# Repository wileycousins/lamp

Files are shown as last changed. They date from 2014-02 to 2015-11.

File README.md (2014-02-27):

# lamp
Another object from [Wiley Cousins](https://wileycousins.com) and [Trig Projects](http://trigprojects.com)

Lamp is a smart LED lamp system that has two jobs: letting you know about things and looking pretty. Currently in development.

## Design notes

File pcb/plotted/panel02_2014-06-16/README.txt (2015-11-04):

Lamp v0.2 Panel
Wiley Cousins, LLC.
2014-06-16

Prepared by Michael Cousins
michael@wileycousins.com
(281) 210-6984

File overview:
lamp-main-append-F_Cu.gtl       -  top copper
lamp-main-append-F_Mask.gts     -  top soldermask
lamp-main-append-F_SilkS.gto    -  top silkscreen
lamp-main-append-B_Cu.gbl       -  bottom copper
lamp-main-append-B_Mask.gts     -  bottom soldermask
lamp-main-append-Edge_Cuts.gbr  -  board outline
lamp-main-append-Eco2_User.gbr  -  dimensions
lamp-main-append.drl            -  drill file

Board outline:
  - 0.01" lines indicate outline
  - 0.005" lines indicate score lines

Drill file:
  - Excellon format
  - 2:4 precision
  - No zero suppression

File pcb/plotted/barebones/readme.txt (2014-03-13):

Lamp v0.1 Bare-bones Panel
Wiley Cousins, LLC.
2014-03-13

Prepared by Michael Cousins
michael@wileycousins.com
(281) 210-6984

File overview:
lamp-pcb-F_Cu.gtl       -  top copper
lamp-pcb-B_Cu.gbl       -  bottom copper
lamp-pcb-Edge_Cuts.gbr  -  board outline
lamp-pcb.drl            -  drill file

Drill file:
  - Excellon format
  - 2:4 precision
  - No zero suppression

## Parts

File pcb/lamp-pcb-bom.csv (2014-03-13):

24pF,2,"C2 C3",,Samsung Electro-Mechanics America, Inc,CL10C240JB8NCNC,Digikey,1276-2242-1-ND,http://www.digikey.com/product-detail/en/CL10C240JB8NCNC/1276-2242-1-ND/3890328
0.1uF,1,"C1",,On Hand
0.1uF,6,"C4 C5 C6 C9 C10 C11",,On hand
10uF,1,"C7",,Taiyo Yuden,TMK316F106ZL-T,Digikey,587-1353-1-ND,http://www.digikey.com/product-detail/en/TMK316F106ZL-T/587-1353-1-ND/931130
22uF,1,"C8",,Taiyo Yuden,LMK316F226ZL-T,Digikey,587-1356-1-ND,http://www.digikey.com/product-detail/en/LMK316F226ZL-T/587-1356-1-ND/931133
ATMEGA328P,1,"IC1",
LM1117,1,"IC2",,Diodes Incorporated,AZ1117CH-5.0TRG1,Digikey,AZ1117CH-5.0TRG1DICT-ND,http://www.digikey.com/product-detail/en/AZ1117CH-5.0TRG1/AZ1117CH-5.0TRG1DICT-ND/4505207
TLC5973,1,"IC3",,Texas Instruments,TLC5973D
5V_OUT,1,"J1",
LED_CARD_BOTTOM,1,"J2",
CREE-CLV6A-FKB,2,"LED1 LED2",,Cree,CLV6A-FKB-CK1P1G1BB7R3R3,Digikey,CLV6A-FKB-CK1P1G1BB7R3R3CT-ND,http://www.digikey.com/product-detail/en/CLV6A-FKB-CK1P1G1BB7R3R3/CLV6A-FKB-CK1P1G1BB7R3R3CT-ND/2166014
HEART,1,"LED3",,On hand
PWR,1,"LED4",,On hand
7-12V_IN,1,"P1",
AVR_ISP,1,"P2",
SERIAL,1,"P3",
LEDSTACK,3,"P4 P5 P6",
LED_CARD_TOP,1,"P7",
SER_SHORT,1,"P8",
1kΩ,3,"R5 R6 R7",,On hand
2kΩ,1,"R4",,On hand
10kΩ,3,"R1 R2 R3",,On hand
TOP,1,"S1",,C&K Components,JS102011SAQN,Digikey,401-1999-1-ND,http://www.digikey.com/product-detail/en/JS102011SAQN/401-1999-1-ND/1640114
14.7456MHz,1,"Y1",,Abracon Corporation,ABLS-14.7456MHZ-B4-T,Digikey,535-10223-1-ND,http://www.digikey.com/product-detail/en/ABLS-14.7456MHZ-B4-T/535-10223-1-ND/2184258

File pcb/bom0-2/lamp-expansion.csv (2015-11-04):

Id | Designator | Package | Quantity | Designation | Supplier and ref
1 | AE1 | johanson:JOHANSON-2500AT44M0400_2.4GHz-chip-antenna | 1 | 2500AT44M0400E
2 | C1,C9,C15,C27,C28 | passive-smd:0603(1608m) | 5 | 1uF
3 | C4,C14,C16,C30 | passive-smd:0603(1608m) | 4 | 0.1uF
4 | C5,C6,C18 | passive-smd:0603(1608m) | 3 | 47pF
5 | C7,C13,C8,C31 | passive-smd:1206(3216m) | 4 | 10uF
6 | C19,C3 | capacitor:PANA-D_CHEMI-F_SM-ALUMINUM | 2 | 100uF
7 | C20 | passive-smd:1206(3216m) | 1 | 22uF
8 | C22 | passive-smd:0603(1608m) | 1 | 2.2pF
9 | C24 | passive-smd:0603(1608m) | 1 | 10pF
10 | C26 | passive-smd:0603(1608m) | 1 | DNP(10pF)
11 | F1 | passive-smd:1206(3216m) | 1 | 2A
12 | IC2 | sot:SOT23-5 | 1 | MCP73811
13 | IC6 | sot:SOT223 | 1 | LM1117_5.0
14 | IC7 | sop:SSOP16 | 1 | FT230X_SOP
15 | IC9 | texas:CC3000 | 1 | CC3000
16 | J1 | connect-sm:MICROUSB_sm | 1 | MICROUSB
17 | J3 | sip:SIP6 | 1 | SERIAL
18 | J4 | sip:SIP5 | 1 | 5PIN_INPUT
19 | J5,J7 | sip:SIP2 | 2 | 2PIN_POWER
20 | J8 | connect-thru:2x3-ARRAY_P100mil | 1 | AVR_ISP
21 | J9 | connect-sm:U.FL-COAX | 1 | UF.L
22 | JP3 | jumper:SOLDER-JUMPER_2-WAY | 1 | MODE-SEL
23 | L2 | passive-smd:0603(1608m) | 1 | DNP
24 | L3 | passive-smd:0603(1608m) | 1 | 2.2nH
25 | LED1 | led:0603(1608m)-SM-LED | 1 | YEL
26 | LED2 | led:0603(1608m)-SM-LED | 1 | GRN
27 | Q1 | sot:SOT23 | 1 | 2N7002
28 | R1 | passive-smd:0603(1608m) | 1 | 100kΩ
29 | R2,R3 | passive-smd:0603(1608m) | 2 | 27Ω
30 | R4 | passive-smd:0603(1608m) | 1 | 10k
31 | R5,R10 | passive-smd:0603(1608m) | 2 | 10kΩ
32 | R6 | passive-smd:0603(1608m) | 1 | 47kΩ
33 | R7 | passive-smd:0603(1608m) | 1 | 51k
34 | R8,R9 | passive-smd:0603(1608m) | 2 | 330Ω
35 | R12,R13 | passive-smd:0603(1608m) | 2 | 0Ω
36 | TP1,TP2,TP3,TP4,TP5 | connect-thru:1-PIN | 5 | TEST
37 | TP6,TP7,TP8,TP9,TP10 | connect-thru:1-PIN | 5 | PIN
38 | C29 | passive-smd:0603(1608m) | 1 | 2.2nF
39 | IC1 | sop:SOP8_ep | 1 | PAM2421
40 | L1 | inductor:SM-INDUCTOR_6mmX6mm | 1 | 6.8uH
41 | D2,D6 | diode:MICROSMP | 2 | 2A
42 | D3,D4 | diode:DO-214AC | 2 | 3A
43 | IC3 | sot:CHIPFET-1206-8 | 1 | NTHD3101F
44 | J2 | connect-thru:CUI-PJ-102A_dc-barrel-jack | 1 | DCIN
45 | VR2,VR3,VR1 | bourns:BOURNS-PTA2043_20mm-slide-pot | 3 | 100kΩ
46 | BT1 | connect-thru:JST-S2B-PH-K_right-angle-jack | 1 | LIPO
47 | S1 | switch:SPST-2-PIN_6mm_thru | 1 | SPST

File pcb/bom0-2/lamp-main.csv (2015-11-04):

Id | Designator | Package | Quantity | Designation | Supplier and ref
1 | IC1 | qfp:TQFP32_P0.8mm | 1 | ATMEGA328P
2 | IC2 | sot:SOT223 | 1 | DNP(LM1117_3.3)
3 | P1 | sip:SIP2 | 1 | VLED_IN
4 | P2 | connect-thru:2x3-ARRAY_P100mil | 1 | AVR_ISP
5 | P3 | sip:SIP6 | 1 | SERIAL
6 | P4,P5,P6 | sip:SIP5 | 3 | LEDSTACK
7 | P7 | sip:SIP5 | 1 | USER-INPUT
8 | P8 | sip:SIP2 | 1 | EXTRA-ADC
9 | P10 | sip:SIP2 | 1 | V_IN
10 | Y1 | crystal:ABRACON-ABM2_xtal | 1 | 8MHz
11 | JP1 | jumper:SOLDER-JUMPER_1-WAY | 1 | VLED-VIN-JUMP
12 | C1,C4,C5,C6,C9 | capacitor:0603(1608m)-CHIP-CAP | 5 | 0.1uF
13 | C2,C3 | capacitor:0603(1608m)-CHIP-CAP | 2 | 24pF
14 | C7 | capacitor:1206(3216m)-CHIP-CAP | 1 | DNP(10uF)
15 | C8 | capacitor:1206(3216m)-CHIP-CAP | 1 | DNP(22uF)
16 | R1,R2,R3 | resistor:0603(1608m)-CHIP-RESISTOR | 3 | 10kΩ
17 | R6,R7 | resistor:0603(1608m)-CHIP-RESISTOR | 2 | 1kΩ
18 | LED1,LED2 | led:0603(1608m)-SM-LED | 2 | RED

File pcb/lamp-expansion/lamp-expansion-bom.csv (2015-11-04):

Source: | /media/sf_projects/lamp/pcb/lamp-expansion/lamp-expansion.sch
Date: | Fri 15 Aug 2014 07:13:58 PM EDT
Tool: | eeschema (2014-03-19 BZR 4756)-product
Component Count: | 67
Individual Components:
Item | Qty | Reference(s) | Value | LibPart | Footprint | Datasheet | Distrib. Part | Distributor | Manuf. Part | Manufacturer
 |  | AE1 | 2500AT44M0400E | standard:ANTENNA | johanson:JOHANSON-2500AT44M0400_2.4GHz-chip-antenna |  | 712-1403-1-ND | Digikey | 2500AT44M0400E | Johanson Technology Inc
 |  | BT1 | LIPO | connector:LIPO | connect-thru:JST-S2B-PH-K_right-angle-jack
 |  | C1 | 1uF | standard:C | passive-smd:0603(1608m)
 |  | C13 | 10uF | standard:C_POL | passive-smd:1206(3216m) |  | 587-1353-1-ND | Digikey | TMK316F106ZL-T | Taiyo Yuden
 |  | C14 | 0.1uF | standard:C | passive-smd:0603(1608m)
 |  | C15 | 1uF | standard:C | passive-smd:0603(1608m)
 |  | C16 | 0.1uF | standard:C | passive-smd:0603(1608m)
 |  | C18 | 47pF | standard:C | passive-smd:0603(1608m)
 |  | C19 | 100uF | standard:C_POL | capacitor:PANA-D_CHEMI-F_SM-ALUMINUM |  | 565-2089-1-ND | Digikey | EMVA160ADA101MF55G | United Chemi-Con
 |  | C20 | 22uF | standard:C_POL | passive-smd:1206(3216m) |  | 587-1356-1-ND | Digikey | LMK316F226ZL-T | Taiyo Yuden
 |  | C22 | 2.2pF | standard:C | passive-smd:0603(1608m)
 |  | C24 | 10pF | standard:C | passive-smd:0603(1608m)
 |  | C26 | DNP(10pF) | standard:C | passive-smd:0603(1608m)
 |  | C27 | 1uF | standard:C | passive-smd:0603(1608m)
 |  | C28 | 1uF | standard:C | passive-smd:0603(1608m)
 |  | C29 | 2.2nF | standard:C | passive-smd:0603(1608m)
 |  | C3 | 100uF | standard:C_POL | capacitor:PANA-D_CHEMI-F_SM-ALUMINUM |  | 565-2089-1-ND | Digikey | EMVA160ADA101MF55G | United Chemi-Con
 |  | C30 | 0.1uF | standard:C | passive-smd:0603(1608m)
 |  | C31 | 10uF | standard:C | passive-smd:1206(3216m)
 |  | C4 | 0.1uF | standard:C | passive-smd:0603(1608m)
 |  | C5 | 47pF | standard:C | passive-smd:0603(1608m)
 |  | C6 | 47pF | standard:C | passive-smd:0603(1608m)
 |  | C7 | 10uF | standard:C_POL | passive-smd:1206(3216m) |  | 587-1353-1-ND | Digikey | Taiyo Yuden | TMK316F106ZL-T
 |  | C8 | 10uF | standard:C | passive-smd:1206(3216m)
 |  | C9 | 1uF | standard:C | passive-smd:0603(1608m)
 |  | D2 | 2A | standard:D_SCHOTTKY | diode:MICROSMP |  | MSS2P2-M3/89AGICT-ND | Digikey | MSS2P2-M3/89A | Vishay
 |  | D3 | 3A | standard:D_SCHOTTKY | diode:DO-214AC |  | RB056L-40TE25CT-ND | Digikey | RB056L-40TE25 | Rohm Semiconductor
 |  | D4 | 3A | standard:D_SCHOTTKY | diode:DO-214AC |  | RB056L-40TE25CT-ND | Digikey | RB056L-40TE25 | Rohm Semiconductor
 |  | D6 | 2A | standard:D_SCHOTTKY | diode:MICROSMP |  | MSS2P2-M3/89AGICT-ND | Digikey | MSS2P2-M3/89A | Vishay
 |  | F1 | 2A | standard:PTC | passive-smd:1206(3216m)
 |  | IC1 | PAM2421 | diode-inc-ic:PAM242X | sop:SOP8_ep |  |  |  |  | Diodes Inc
 |  | IC2 | MCP73811 | microchip-ic:MCP73811/2 | sot:SOT23-5 |  | MCP73811T-420I/OTCT-ND | Digikey | MCP73811T-420I/OT | Microchip Technology
 |  | IC3 | NTHD3101F | on-semi-ic:NTHD3101F | sot:CHIPFET-1206-8 |  |  |  |  | On Semiconductor
 |  | IC6 | LM1117_5.0 | regulator:LM1117 | sot:SOT223 |  | AZ1117CH-5.0TRG1DICT-ND | Digikey | AZ1117CH-5.0TRG1 | Diodes Incorporated
 |  | IC7 | FT230X_SOP | ftdi-ic:FT230X_SOP | sop:SSOP16
 |  | IC9 | CC3000 | ti-ic:CC3000 | texas:CC3000 | http://www.ti.com/lit/gpn/cc3000 | 296-35512-1-ND | Digikey | CC3000MOD | TI
 |  | J1 | MICROUSB | connector:MICROUSB | connect-sm:MICROUSB_sm
 |  | J2 | DCIN | connector:DC-BARREL-JACK | connect-thru:CUI-PJ-102A_dc-barrel-jack
 |  | J3 | SERIAL | connector:6PIN_FEMALE | sip:SIP6
 |  | J4 | 5PIN_INPUT | connector:5PIN_FEMALE | sip:SIP5
 |  | J5 | 2PIN_POWER | connector:2PIN_FEMALE | sip:SIP2
 |  | J7 | 2PIN_POWER | connector:2PIN_FEMALE | sip:SIP2
 |  | J8 | AVR_ISP | avr-mcu:AVR_ISP | connect-thru:2x3-ARRAY_P100mil
 |  | J9 | UF.L | connector:COAX-JACK | connect-sm:U.FL-COAX
 |  | JP3 | MODE-SEL | standard:JUMPER_3-PIN | jumper:SOLDER-JUMPER_2-WAY
 |  | L1 | 6.8uH | standard:L | inductor:SM-INDUCTOR_6mmX6mm |  | SRN6045-6R8YCT-ND | Digikey | SRN6045-6R8Y | Bourns Inc
 |  | L2 | DNP | standard:L | passive-smd:0603(1608m)
 |  | L3 | 2.2nH | standard:L | passive-smd:0603(1608m)
 |  | LED1 | YEL | standard:LED | led:0603(1608m)-SM-LED
 |  | LED2 | GRN | standard:LED | led:0603(1608m)-SM-LED
 |  | Q1 | 2N7002 | transistor:N-CHAN-MOSFET_SOT | sot:SOT23 |  | 568-5818-1-ND | Digikey | 2N7002P | NXP

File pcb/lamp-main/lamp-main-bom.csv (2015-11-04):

Source: | /media/sf_projects/lamp/pcb/lamp-main/lamp-main.sch
Date: | Fri 15 Aug 2014 04:16:45 PM CDT
Tool: | eeschema (2014-03-19 BZR 4756)-product
Component Count: | 29
Individual Components:
Item | Qty | Reference(s) | Value | LibPart | Footprint | Datasheet | Distrib. Link | Distrib. Part | Distributor | Manuf. Part | Manufacturer
 |  | C1 | 0.1uF | standard:C | capacitor:0603(1608m)-CHIP-CAP |  |  |  | On Hand
 |  | C2 | 24pF | standard:C | capacitor:0603(1608m)-CHIP-CAP |  | http://www.digikey.com/product-detail/en/CL10C240JB8NCNC/1276-2242-1-ND/3890328 | 1276-2242-1-ND | Digikey | CL10C240JB8NCNC | Samsung
 |  | C3 | 24pF | standard:C | capacitor:0603(1608m)-CHIP-CAP |  | http://www.digikey.com/product-detail/en/CL10C240JB8NCNC/1276-2242-1-ND/3890328 | 1276-2242-1-ND | Digikey | CL10C240JB8NCNC | Samsung Electro-Mechanics America, Inc
 |  | C4 | 0.1uF | standard:C | capacitor:0603(1608m)-CHIP-CAP |  |  |  | On hand
 |  | C5 | 0.1uF | standard:C | capacitor:0603(1608m)-CHIP-CAP |  |  |  | On hand
 |  | C6 | 0.1uF | standard:C | capacitor:0603(1608m)-CHIP-CAP |  |  |  | On hand
 |  | C7 | DNP(10uF) | standard:C_POL | capacitor:1206(3216m)-CHIP-CAP |  | http://www.digikey.com/product-detail/en/TMK316F106ZL-T/587-1353-1-ND/931130 | 587-1353-1-ND | Digikey | TMK316F106ZL-T | Taiyo Yuden
 |  | C8 | DNP(22uF) | standard:C_POL | capacitor:1206(3216m)-CHIP-CAP |  | http://www.digikey.com/product-detail/en/LMK316F226ZL-T/587-1356-1-ND/931133 | 587-1356-1-ND | Digikey | LMK316F226ZL-T | Taiyo Yuden
 |  | C9 | 0.1uF | standard:C | capacitor:0603(1608m)-CHIP-CAP |  |  |  | On hand
 |  | IC1 | ATMEGA328P | avr-mcu:ATMEGA328P_TQFP | qfp:TQFP32_P0.8mm |  | http://www.digikey.com/product-detail/en/ATMEGA328P-AU/ATMEGA328P-AU-ND/1832260 | ATMEGA328P-AU-ND | Digikey | ATMEGA328P-AU | Atmel
 |  | IC2 | DNP(LM1117_3.3) | lamp-main-cache:LM1117 | sot:SOT223 | http://www.diodes.com/datasheets/AZ1117C.pdf | http://www.digikey.com/product-detail/en/AZ1117CH-5.0TRG1/AZ1117CH-5.0TRG1DICT-ND/4505207 | AZ1117CH-5.0TRG1DICT-ND | Digikey | AZ1117CH-5.0TRG1 | Diodes Incorporated
 |  | JP1 | VLED-VIN-JUMP | standard:JUMPER_2-PIN | jumper:SOLDER-JUMPER_1-WAY
 |  | LED1 | RED | standard:LED | led:0603(1608m)-SM-LED |  |  |  | On hand
 |  | LED2 | RED | standard:LED | led:0603(1608m)-SM-LED |  |  |  | On hand
 |  | P1 | VLED_IN | connector:2PIN_MALE | sip:SIP2
 |  | P10 | V_IN | connector:2PIN_MALE | sip:SIP2
 |  | P2 | AVR_ISP | avr-mcu:AVR_ISP | connect-thru:2x3-ARRAY_P100mil
 |  | P3 | SERIAL | connector:6PIN_HEADER | sip:SIP6
 |  | P4 | LEDSTACK | connector:5PIN_MALE | sip:SIP5
 |  | P5 | LEDSTACK | connector:5PIN_MALE | sip:SIP5
 |  | P6 | LEDSTACK | connector:5PIN_MALE | sip:SIP5
 |  | P7 | USER-INPUT | connector:5PIN_MALE | sip:SIP5
 |  | P8 | EXTRA-ADC | connector:2PIN_MALE | sip:SIP2

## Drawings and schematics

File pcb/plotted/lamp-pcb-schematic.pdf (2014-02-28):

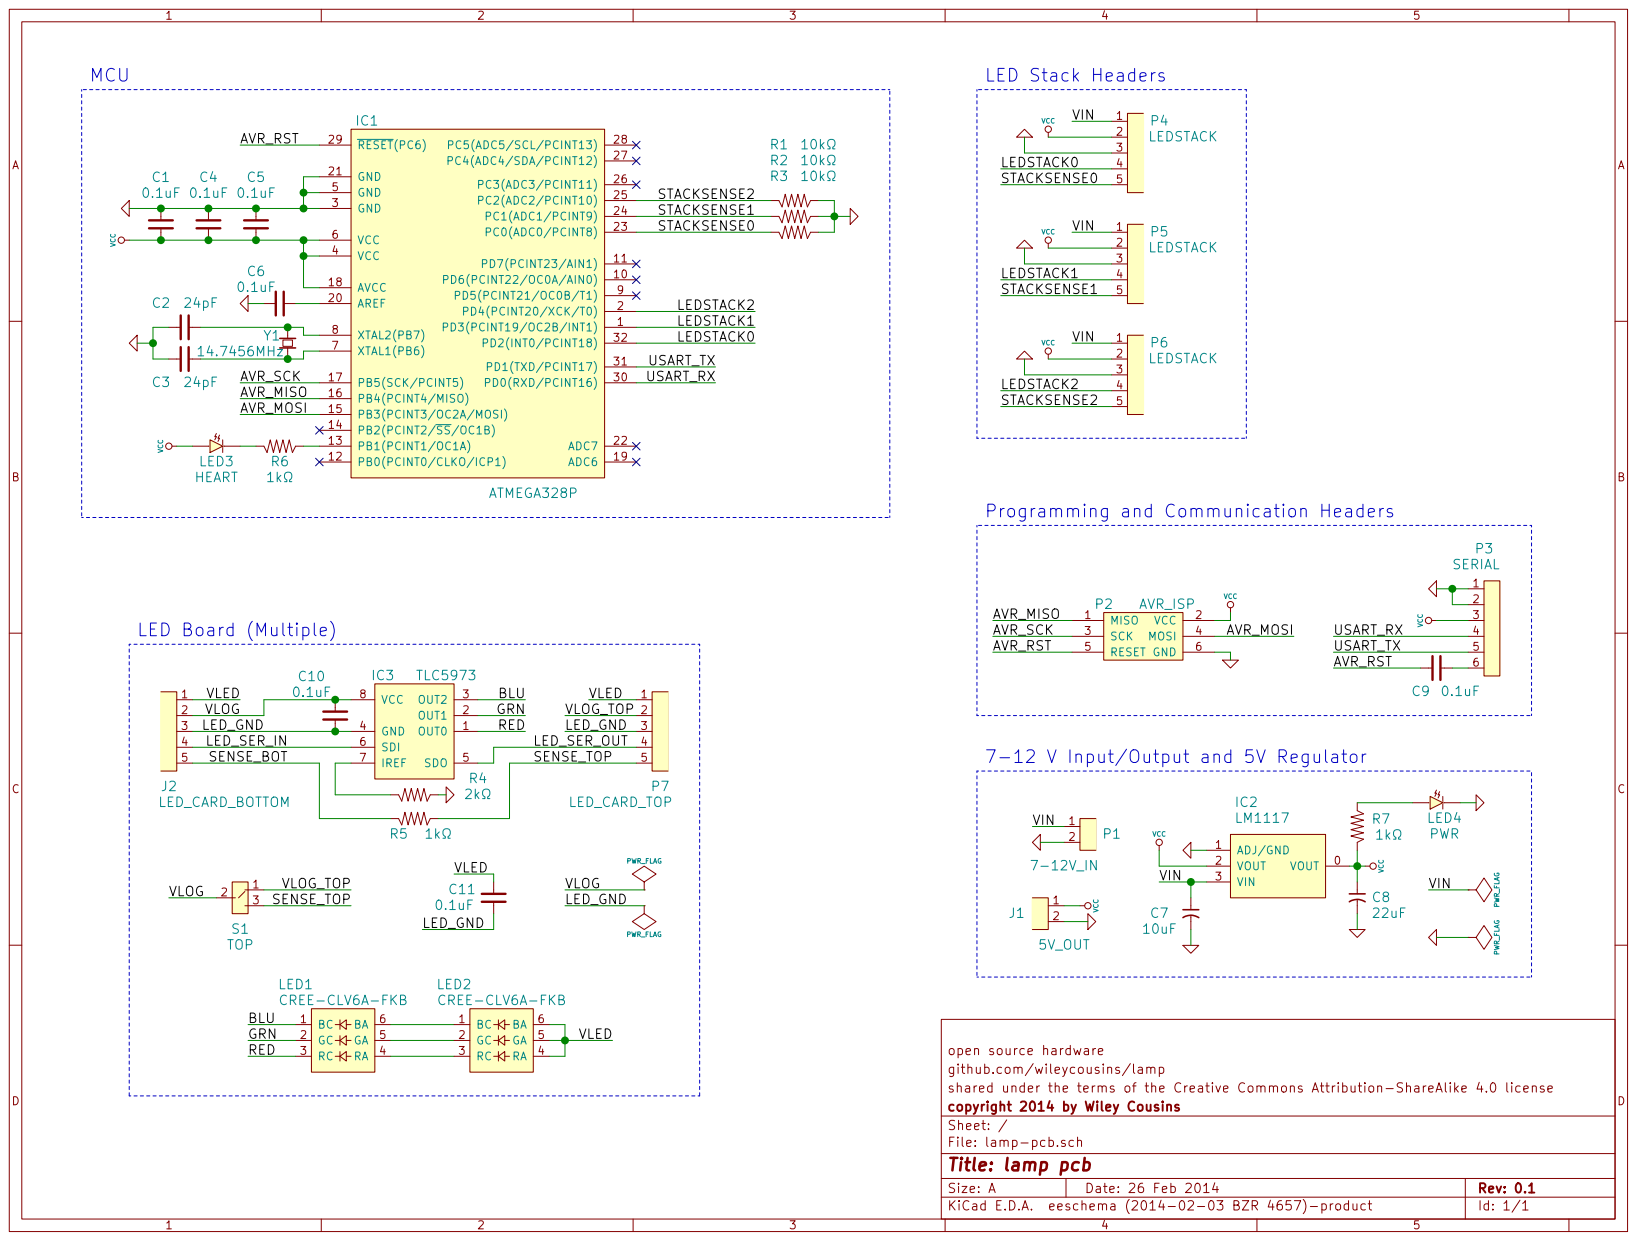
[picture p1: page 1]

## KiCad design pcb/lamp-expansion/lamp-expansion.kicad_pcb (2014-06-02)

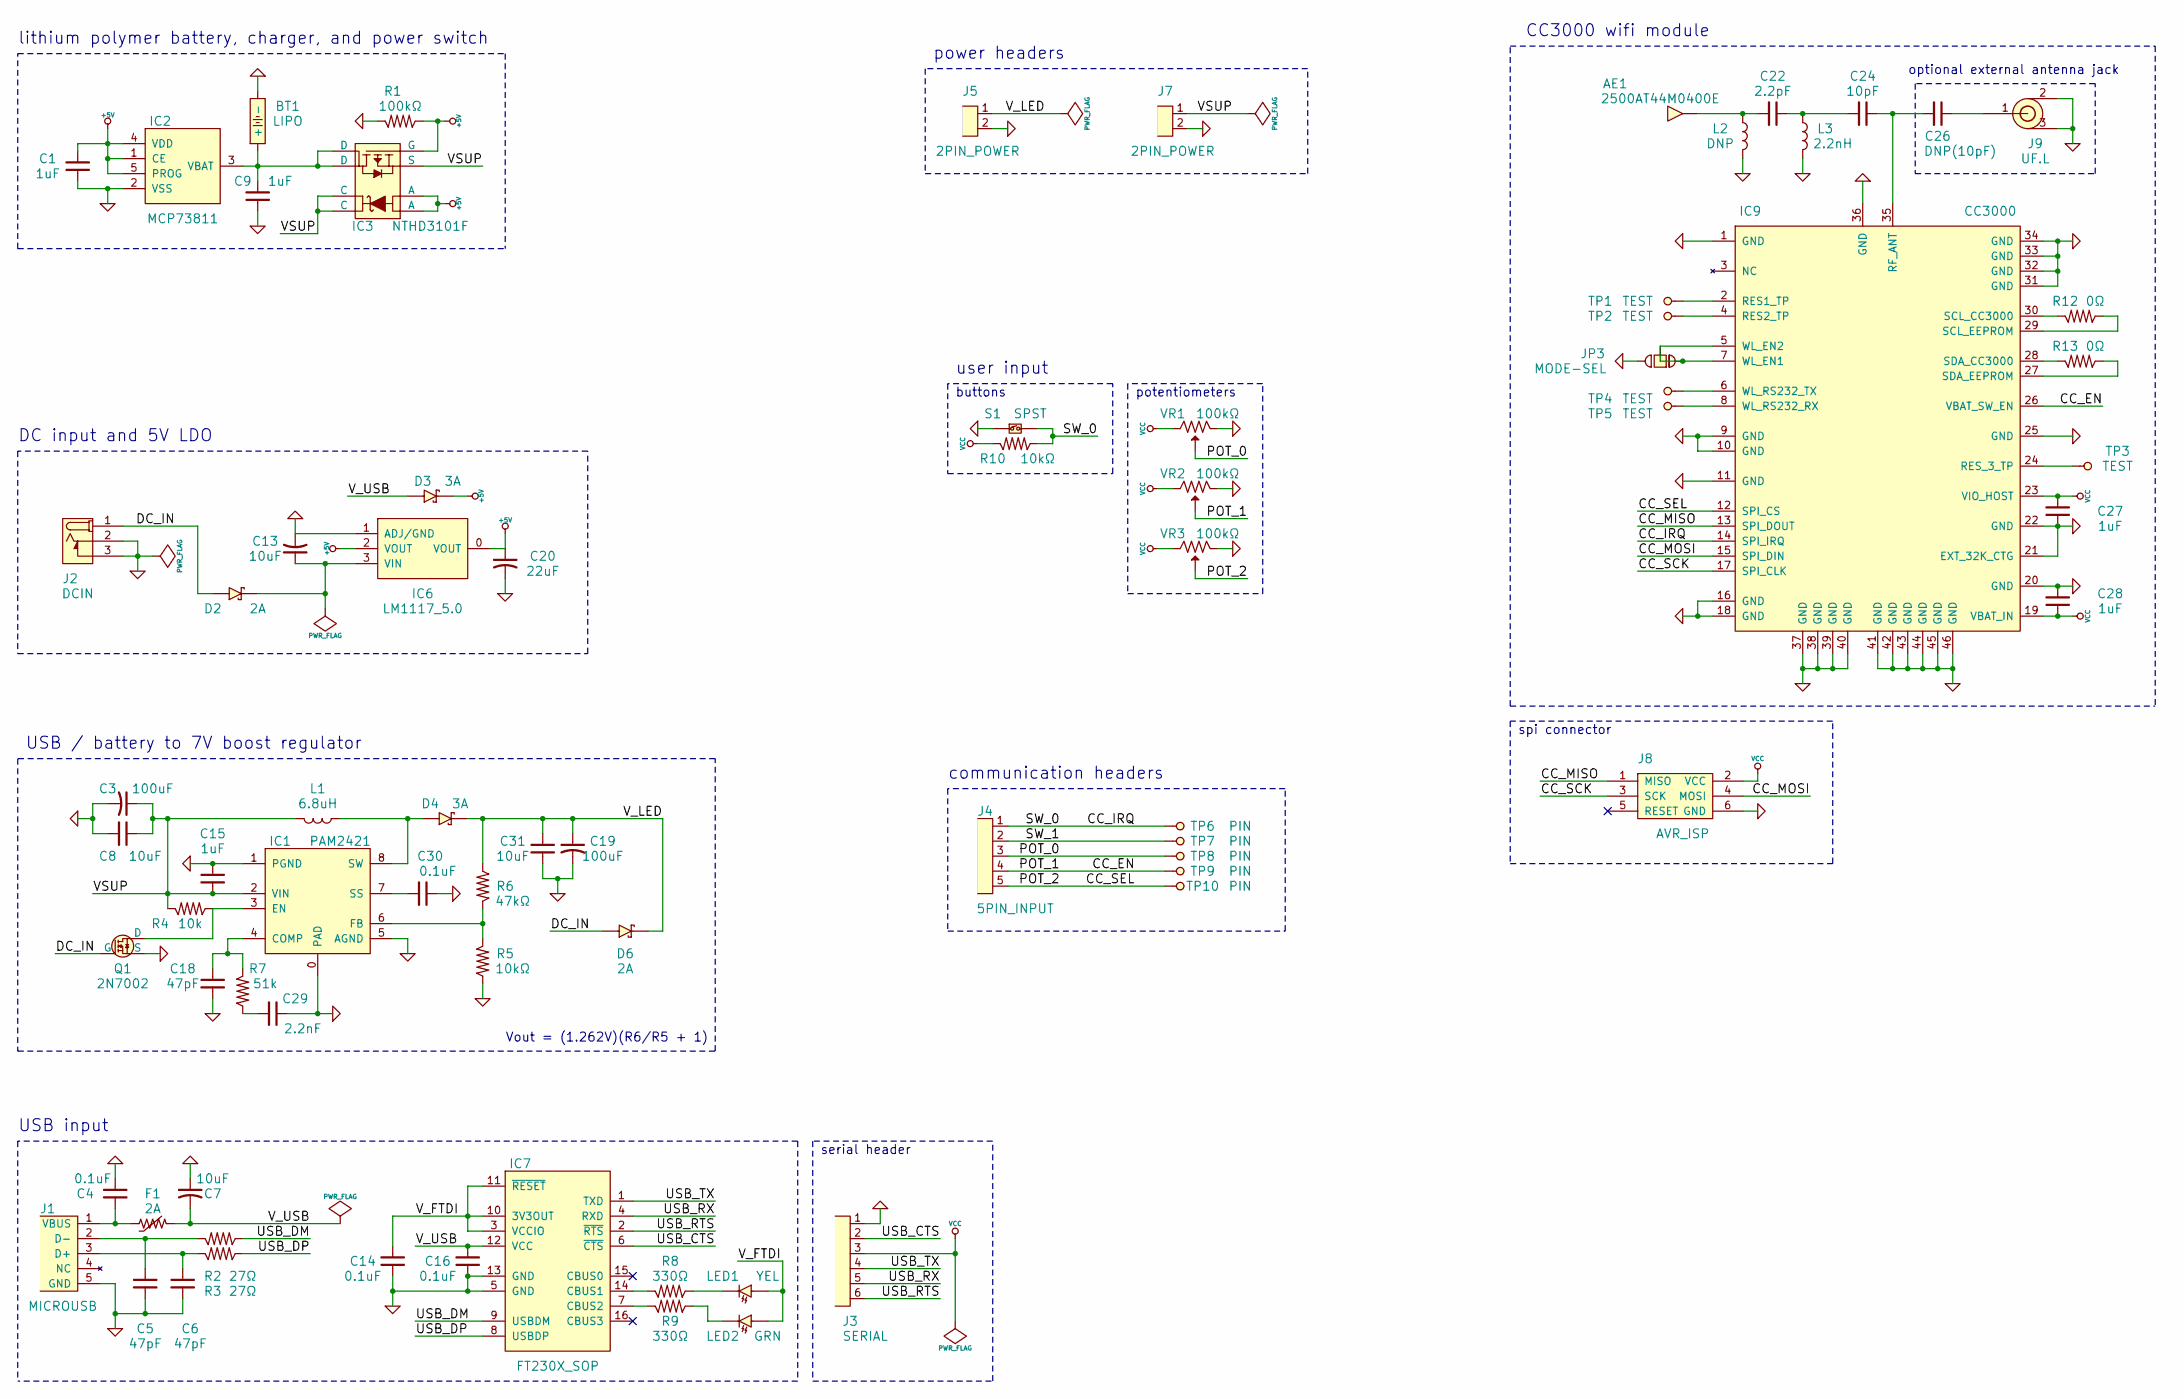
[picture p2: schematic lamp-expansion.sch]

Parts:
AE1: 2500AT44M0400E; Manuf. Part 2500AT44M0400E
BT1: LIPO
C1, C9, C15, C27, C28: 1uF
C3, C19: 100uF; Manuf. Part EMVA160ADA101MF55G
C4, C14, C16, C30: 0.1uF
C5, C6, C18: 47pF
C7: 10uF; Manuf. Part Taiyo Yuden
C8, C31: 10uF
C13: 10uF; Manuf. Part TMK316F106ZL-T
C20: 22uF; Manuf. Part LMK316F226ZL-T
C22: 2.2pF
C24: 10pF
C26: DNP(10pF)
C29: 2.2nF
D2, D6: 2A; Manuf. Part MSS2P2-M3/89A
D3, D4: 3A; Manuf. Part RB056L-40TE25
F1: 2A
IC1: PAM2421
IC2: MCP73811; Manuf. Part MCP73811T-420I/OT
IC3: NTHD3101F
IC6: LM1117_5.0; Manuf. Part AZ1117CH-5.0TRG1
IC7: FT230X_SOP
IC9: CC3000; Manuf. Part CC3000MOD
J1: MICROUSB
J2: DCIN
J3: SERIAL
J4: 5PIN_INPUT
J5, J7: 2PIN_POWER
J8: AVR_ISP
J9: UF.L
JP3: MODE-SEL
L1: 6.8uH; Manuf. Part SRN6045-6R8Y
L2: DNP
L3: 2.2nH
LED1: YEL
LED2: GRN
Q1: 2N7002; Manuf. Part 2N7002P,215
R1: 100kΩ
R2, R3: 27Ω
R4: 10k
R5, R10: 10kΩ
R6: 47kΩ
R7: 51k
R8, R9: 330Ω
R12, R13: 0Ω
S1: SPST
TP1, TP2, TP3, TP4, TP5: TEST
TP6, TP7, TP8, TP9, TP10: PIN
VR1, VR2, VR3: 100kΩ; Manuf. Part PTA2043-2015CPB103

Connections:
+5V: C1.1, C20.1, D3.1 (C), IC2.1 (CE), IC2.4 (VDD), IC2.5 (PROG), IC3.1 (A), IC3.2 (A), IC3.4 (G), IC6.0 (VOUT), IC6.2 (VOUT), R1.2
/CC_EN: IC9.26 (VBAT_SW_EN), J4.4, TP9.1, VR2.2 (W)
/CC_IRQ: IC9.14 (SPI_IRQ), J4.1, R10.2, S1.2, TP6.1
/CC_MISO: IC9.13 (SPI_DOUT), J8.1 (MISO)
/CC_MOSI: IC9.15 (SPI_DIN), J8.4 (MOSI)
/CC_SCK: IC9.17 (SPI_CLK), J8.3 (SCK)
/CC_SEL: IC9.12 (SPI_CS), J4.5, TP10.1, VR3.2 (W)
/DC_IN: D2.2 (A), D6.2 (A), J2.1 (POLE), Q1.1 (G)
/POT_0: J4.3, TP8.1, VR1.2 (W)
/SW_1: J4.2, TP7.1
/USB_CTS: IC7.6 (~CTS~), J3.2
/USB_DM: IC7.9 (USBDM), R2.2
/USB_DP: IC7.8 (USBDP), R3.2
/USB_RTS: IC7.2 (~RTS~), J3.6
/USB_RX: IC7.4 (RXD), J3.5
/USB_TX: IC7.1 (TXD), J3.4
/VSUP: C3.1, C8.1, C15.2, IC1.2 (VIN), IC3.3 (S), IC3.7 (C), IC3.8 (C), J7.1, L1.2, R4.1
/V_FTDI: C14.1, IC7.3 (VCCIO), IC7.10 (3V3OUT), IC7.11 (~RESET~), LED1.2 (A), LED2.2 (A)
/V_LED: C19.1, C31.1, D4.1 (C), D6.1 (C), J5.1, R6.2
/V_USB: C7.2, C16.1, D3.2 (A), F1.2, IC7.12 (VCC)
GND: BT1.2 (-), C1.2, C3.2, C4.1, C5.2, C6.2, C7.1, C8.2, C9.2, C13.2, C14.2, C15.1, C16.2, C18.2, C19.2, C20.2, C27.2, C28.1, C29.1, C30.2, C31.2, IC1.0 (PAD), IC1.1 (PGND), IC1.5 (AGND), IC2.2 (VSS), IC6.1 (ADJ/GND), IC7.5 (GND), IC7.13 (GND), IC9.1 (GND), IC9.9 (GND), IC9.10 (GND), IC9.11 (GND), IC9.16 (GND), IC9.18 (GND), IC9.20 (GND), IC9.21 (EXT_32K_CTG), IC9.22 (GND), IC9.25 (GND), IC9.31 (GND), IC9.32 (GND), IC9.33 (GND), IC9.34 (GND), IC9.36 (GND), IC9.37 (GND), IC9.38 (GND), IC9.39 (GND), IC9.40 (GND), IC9.41 (GND), IC9.42 (GND), IC9.43 (GND), IC9.44 (GND), IC9.45 (GND), IC9.46 (GND), J1.5 (GND), J2.2 (OUT), J2.3 (OUT), J3.1, J5.2, J7.2, J8.6 (GND), J9.2, J9.3, JP3.3, L2.2, L3.2, Q1.2 (S), R1.1, R5.2, S1.1, VR1.3 (E2), VR2.3 (E2), VR3.3 (E2)
unnamed: AE1.1, C22.1, L2.1
unnamed: BT1.1 (+), C9.1, IC2.3 (VBAT), IC3.5 (D), IC3.6 (D)
unnamed: C4.2, F1.1, J1.1 (VBUS)
unnamed: C5.1, J1.2 (D-), R2.1
unnamed: C6.1, J1.3 (D+), R3.1
unnamed: C13.1, D2.1 (C), IC6.3 (VIN)
unnamed: C18.1, IC1.4 (COMP), R7.1
unnamed: C22.2, C24.2, L3.1
unnamed: C24.1, C26.1, IC9.35 (RF_ANT)
unnamed: C26.2, J9.1 (CENTER)
unnamed: C29.2, R7.2
unnamed: C30.1, IC1.7 (SS)
unnamed: D4.2 (A), IC1.8 (SW), L1.1
unnamed: IC1.3 (EN), Q1.3 (D), R4.2
unnamed: IC1.6 (FB), R5.1, R6.1
unnamed: IC7.7 (CBUS2), R9.1
unnamed: IC7.14 (CBUS1), R8.1
unnamed: IC9.2 (RES1_TP), TP1.1
unnamed: IC9.4 (RES2_TP), TP2.1
unnamed: IC9.5 (WL_EN2), IC9.7 (WL_EN1), JP3.1, JP3.2
unnamed: IC9.6 (WL_RS232_TX), TP4.1
unnamed: IC9.8 (WL_RS232_RX), TP5.1
unnamed: IC9.24 (RES_3_TP), TP3.1
unnamed: IC9.27 (SDA_EEPROM), R13.2
unnamed: IC9.28 (SDA_CC3000), R13.1
unnamed: IC9.29 (SCL_EEPROM), R12.2
unnamed: IC9.30 (SCL_CC3000), R12.1
unnamed: LED1.1 (C), R8.2
unnamed: LED2.1 (C), R9.2
VCC: C27.1, C28.2, IC9.19 (VBAT_IN), IC9.23 (VIO_HOST), J3.3, J8.2 (VCC), R10.1, VR1.1 (E1), VR2.1 (E1), VR3.1 (E1)

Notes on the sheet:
USB input
DC input and 5V LDO
lithium polymer battery, charger, and power switch
optional external antenna jack
CC3000 wifi module
spi connector
USB / battery to 7V boost regulator
power headers
serial header
potentiometers
buttons
user input
Vout = (1.262V)(R6/R5 + 1)
communication headers

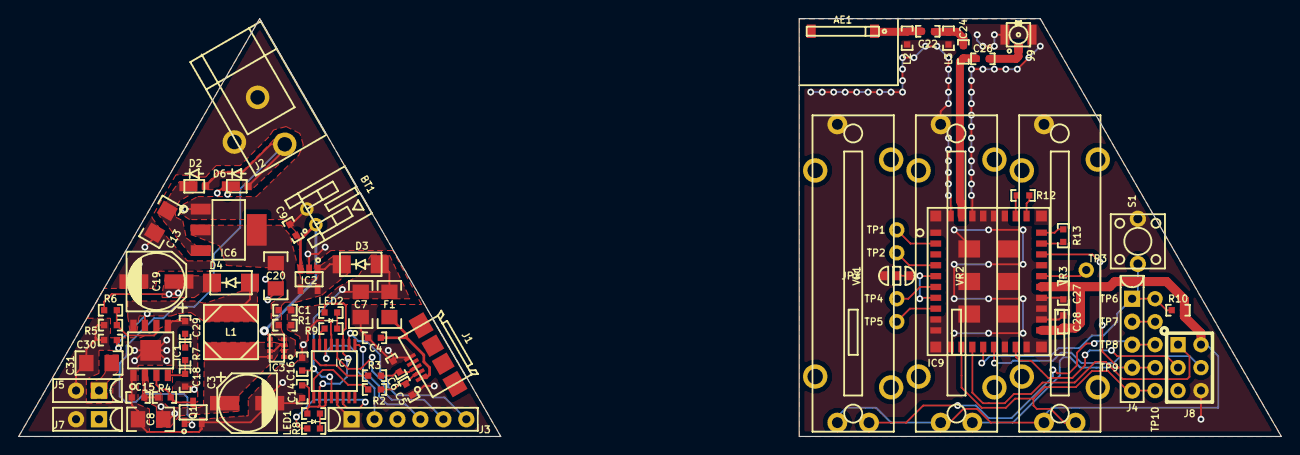
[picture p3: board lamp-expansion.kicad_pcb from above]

Board: 2 copper layers, 139.7 x 46.2 mm, 77 parts (0 on the bottom side), 51 nets.

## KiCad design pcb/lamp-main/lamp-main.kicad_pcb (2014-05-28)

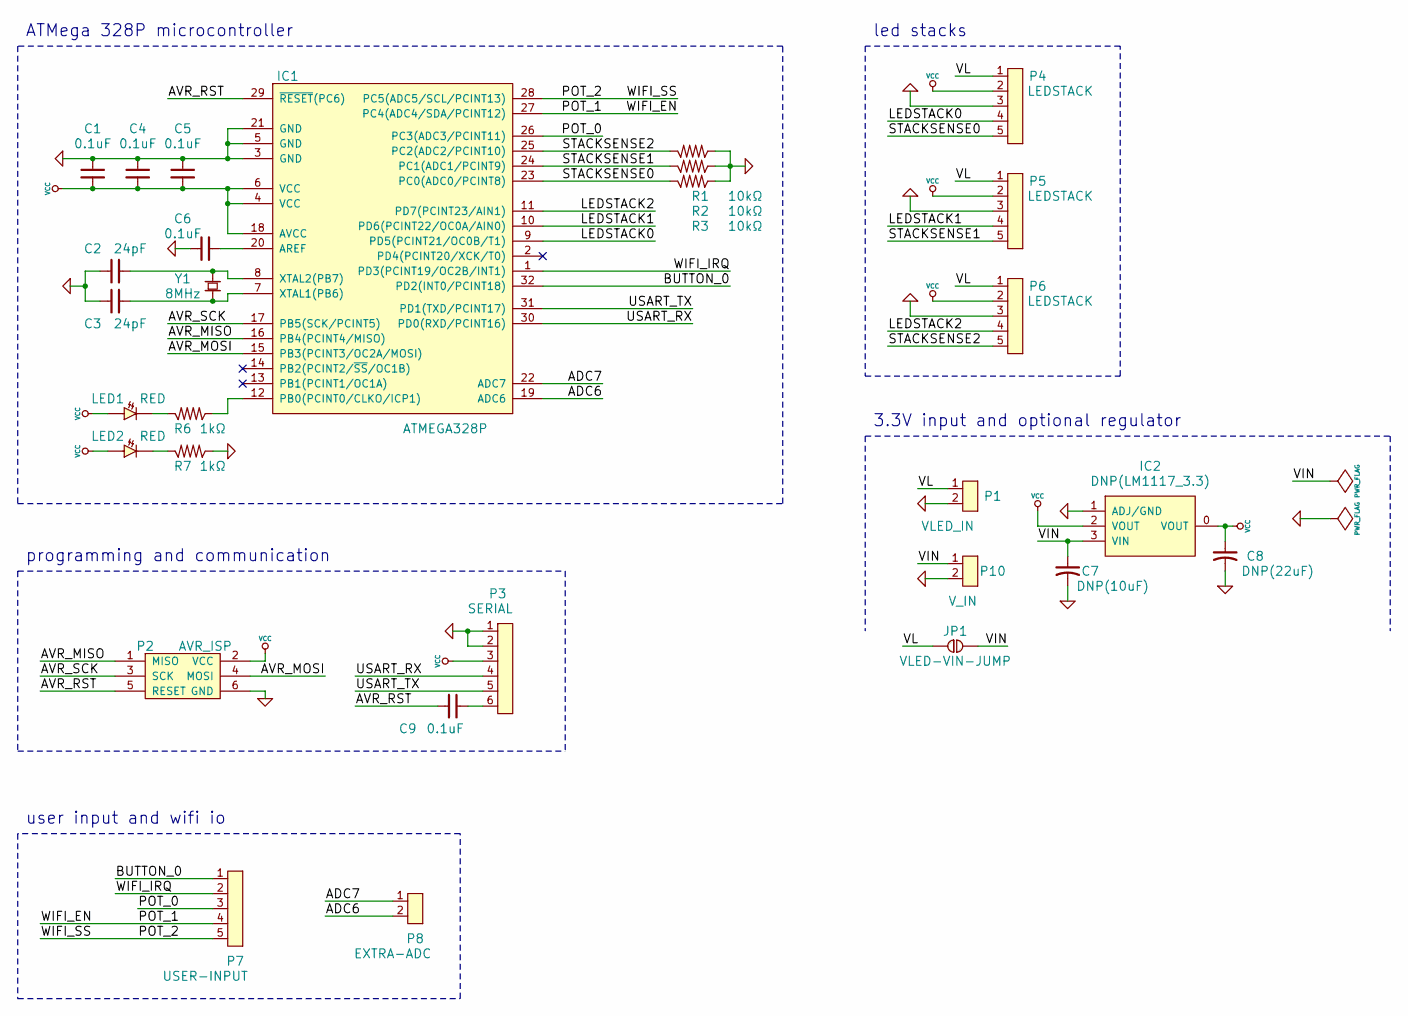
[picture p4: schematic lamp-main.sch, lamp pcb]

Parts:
C1, C4, C5, C6, C9: 0.1uF
C2, C3: 24pF; Manuf. Part CL10C240JB8NCNC
C7: DNP(10uF); Manuf. Part TMK316F106ZL-T
C8: DNP(22uF); Manuf. Part LMK316F226ZL-T
IC1: ATMEGA328P; Manufacturer Part ATMEGA328P-AU
IC2: DNP(LM1117_3.3); Manuf. Part AZ1117CH-5.0TRG1
JP1: VLED-VIN-JUMP
LED1, LED2: RED
P1: VLED_IN
P2: AVR_ISP
P3: SERIAL
P4, P5, P6: LEDSTACK
P7: USER-INPUT
P8: EXTRA-ADC
P10: V_IN
R1, R2, R3: 10kΩ
R6, R7: 1kΩ
Y1: 8MHz; Manuf. Part ABM2-8.000MHZ-D4Y-T

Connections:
/ADC6: IC1.19 (ADC6), P8.2
/ADC7: IC1.22 (ADC7), P8.1
/AVR_MISO: IC1.16 (PB4(PCINT4/MISO)), P2.1 (MISO)
/AVR_MOSI: IC1.15 (PB3(PCINT3/OC2A/MOSI)), P2.4 (MOSI)
/AVR_RST: C9.1, IC1.29 (~RESET~(PC6)), P2.5 (RESET)
/AVR_SCK: IC1.17 (PB5(SCK/PCINT5)), P2.3 (SCK)
/BUTTON_0: IC1.32 (PD2(INT0/PCINT18)), P7.1
/LEDSTACK0: IC1.9 (PD5(PCINT21/OC0B/T1)), P4.4
/LEDSTACK1: IC1.10 (PD6(PCINT22/OC0A/AIN0)), P5.4
/LEDSTACK2: IC1.11 (PD7(PCINT23/AIN1)), P6.4
/POT_0: IC1.26 (PC3(ADC3/PCINT11)), P7.3
/POT_1: IC1.27 (PC4(ADC4/SDA/PCINT12)), P7.4
/POT_2: IC1.28 (PC5(ADC5/SCL/PCINT13)), P7.5
/STACKSENSE0: IC1.23 (PC0(ADC0/PCINT8)), P4.5, R3.1
/STACKSENSE1: IC1.24 (PC1(ADC1/PCINT9)), P5.5, R2.1
/STACKSENSE2: IC1.25 (PC2(ADC2/PCINT10)), P6.5, R1.1
/USART_RX: IC1.30 (PD0(RXD/PCINT16)), P3.4
/USART_TX: IC1.31 (PD1(TXD/PCINT17)), P3.5
/VIN: C7.1, IC2.3 (VIN), JP1.2, P10.1
/VL: JP1.1, P1.1, P4.1, P5.1, P6.1
/WIFI_IRQ: IC1.1 (PD3(PCINT19/OC2B/INT1)), P7.2
GND: C1.2, C2.1, C3.1, C4.2, C5.2, C6.1, C7.2, C8.2, IC1.3 (GND), IC1.5 (GND), IC1.21 (GND), IC2.1 (ADJ/GND), P1.2, P2.6 (GND), P3.1, P3.2, P4.3, P5.3, P6.3, P10.2, R1.2, R2.2, R3.2, R7.2
unnamed: C2.2, IC1.8 (XTAL2(PB7)), Y1.2
unnamed: C3.2, IC1.7 (XTAL1(PB6)), Y1.1
unnamed: C6.2, IC1.20 (AREF)
unnamed: C9.2, P3.6
unnamed: IC1.12 (PB0(PCINT0/CLKO/ICP1)), R6.2
unnamed: LED1.1 (C), R6.1
unnamed: LED2.1 (C), R7.1
VCC: C1.1, C4.1, C5.1, C8.1, IC1.4 (VCC), IC1.6 (VCC), IC1.18 (AVCC), IC2.0 (VOUT), IC2.2 (VOUT), LED1.2 (A), LED2.2 (A), P2.2 (VCC), P3.3, P4.2, P5.2, P6.2

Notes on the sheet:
3.3V input and optional regulator
programming and communication
led stacks
ATMega 328P microcontroller
user input and wifi io

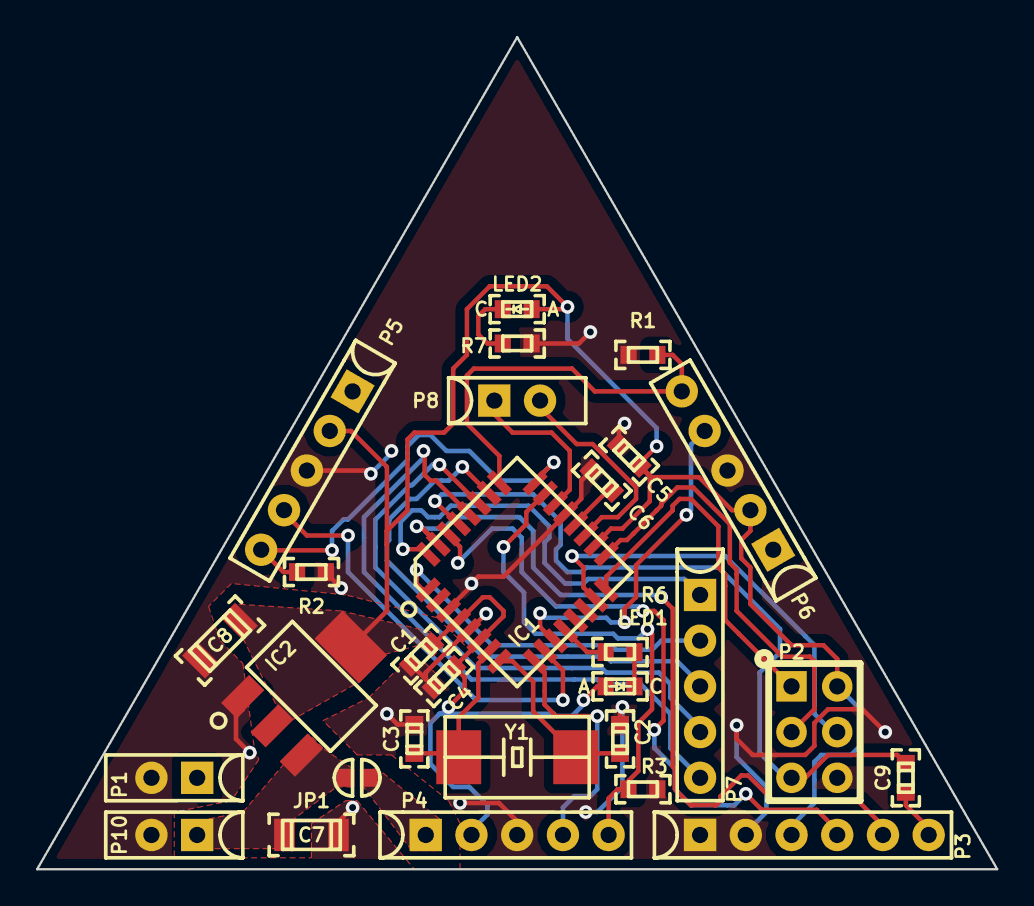
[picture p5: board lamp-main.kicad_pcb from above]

Board: 2 copper layers, 53.3 x 46.2 mm, 29 parts (0 on the bottom side), 30 nets.

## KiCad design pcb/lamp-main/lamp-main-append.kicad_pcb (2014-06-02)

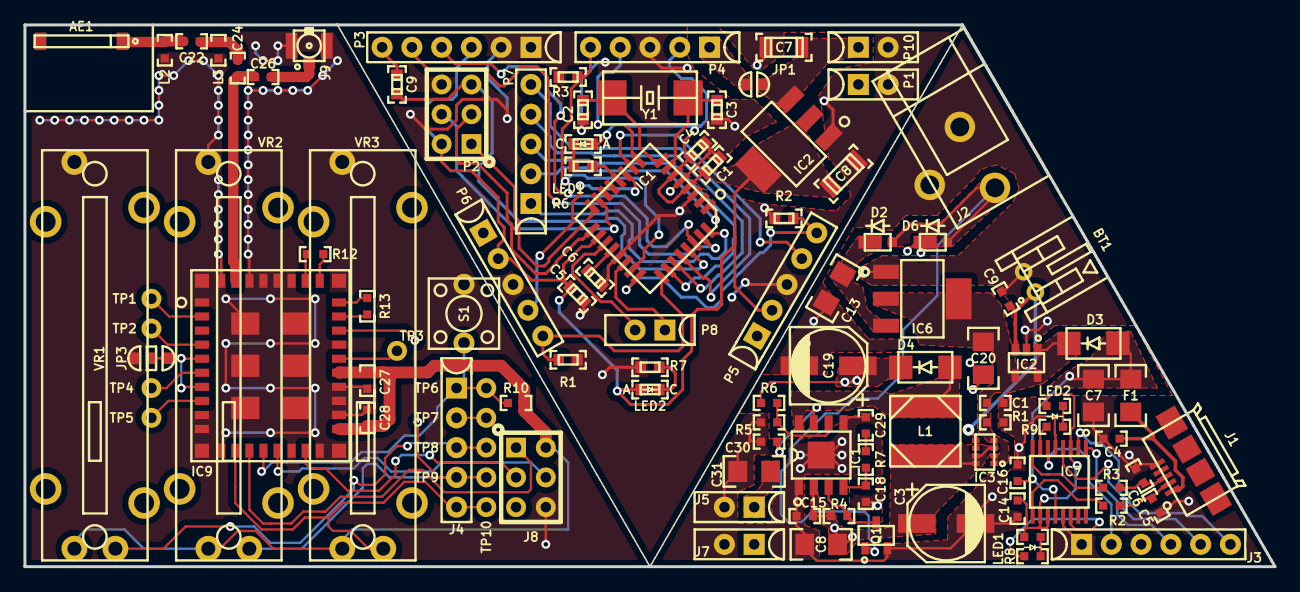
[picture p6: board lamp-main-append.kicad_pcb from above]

Board: 2 copper layers, 106.7 x 46.2 mm, 106 parts (0 on the bottom side), 51 nets.

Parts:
AE1: 2500AT44M0400E; JOHANSON-2500AT44M0400_2.4GHz-chip-antenna
BT1: LIPO; JST-S2B-PH-K_right-angle-jack
C1, C9, C15, C27, C28: 1uF; 0603(1608m)
C1#2, C4#2, C5#2, C6#2, C9#2: 0.1uF; 0603(1608m)-CHIP-CAP
C2, C3#2: 24pF; 0603(1608m)-CHIP-CAP
C3, C19: 100uF; PANA-D_CHEMI-F_SM-ALUMINUM
C4, C14, C16, C30: 0.1uF; 0603(1608m)
C5, C6, C18: 47pF; 0603(1608m)
C7, C8, C13, C31: 10uF; 1206(3216m)
C7#2: DNP(10uF); 1206(3216m)-CHIP-CAP
C8#2: DNP(22uF); 1206(3216m)-CHIP-CAP
C20: 22uF; 1206(3216m)
C22: 2.2pF; 0603(1608m)
C24: 10pF; 0603(1608m)
C26: DNP(10pF); 0603(1608m)
C29: 2.2nF; 0603(1608m)
D2, D6: 2A; MICROSMP
D3, D4: 3A; DO-214AC
F1: 2A; 1206(3216m)
IC1: PAM2421; SOP8_ep
IC1#2: ATMEGA328P; TQFP32_P0.8mm
IC2: MCP73811; SOT23-5
IC2#2: DNP(LM1117_3.3); SOT223
IC3: NTHD3101F; CHIPFET-1206-8
IC6: LM1117_5.0; SOT223
IC7: FT230X_SOP; SSOP16
IC9: CC3000
J1: MICROUSB; MICROUSB_sm
J2: DCIN; CUI-PJ-102A_dc-barrel-jack
J3: SERIAL; SIP6
J4: 5PIN_INPUT; SIP5
J5, J7: 2PIN_POWER; SIP2
J8: AVR_ISP; 2x3-ARRAY_P100mil
J9: UF.L; U.FL-COAX
JP1: VLED-VIN-JUMP; SOLDER-JUMPER_1-WAY
JP3: MODE-SEL; SOLDER-JUMPER_2-WAY
L1: 6.8uH; SM-INDUCTOR_6mmX6mm
L2: DNP; 0603(1608m)
L3: 2.2nH; 0603(1608m)
LED1: YEL; 0603(1608m)-SM-LED
LED1#2, LED2#2: RED; 0603(1608m)-SM-LED
LED2: GRN; 0603(1608m)-SM-LED
P1: VLED_IN; SIP2
P2: AVR_ISP; 2x3-ARRAY_P100mil
P3: SERIAL; SIP6
P4, P5, P6: LEDSTACK; SIP5
P7: USER-INPUT; SIP5
P8: EXTRA-ADC; SIP2
P10: V_IN; SIP2
Q1: 2N7002; SOT23
R1: 100kΩ; 0603(1608m)
R1#2, R2#2, R3#2: 10kΩ; 0603(1608m)-CHIP-RESISTOR
R2, R3: 27Ω; 0603(1608m)
R4: 10k; 0603(1608m)
R5, R10: 10kΩ; 0603(1608m)
R6: 47kΩ; 0603(1608m)
R6#2, R7#2: 1kΩ; 0603(1608m)-CHIP-RESISTOR
R7: 51k; 0603(1608m)
R8, R9: 330Ω; 0603(1608m)
R12, R13: 0Ω; 0603(1608m)
S1: SPST; SPST-2-PIN_6mm_thru
TP1, TP2, TP3, TP4, TP5: TEST; 1-PIN
TP6, TP7, TP8, TP9, TP10: PIN; 1-PIN
VR1, VR2, VR3: 100kΩ; BOURNS-PTA2043_20mm-slide-pot
Y1: 8MHz; ABRACON-ABM2_xtal

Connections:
+5V: C1.1, C1#2.1, C4#2.1, C5#2.1, C8#2.1, C20.1, D3.1, IC1#2.4, IC1#2.6, IC1#2.18, IC2.1, IC2.4, IC2.5, IC2#2.0, IC2#2.2, IC3.1, IC3.2, IC3.4, IC6.0, IC6.2, LED1#2.2, LED2#2.2, P2.2, P3.3, P4.2, P5.2, P6.2, R1.2
/CC_EN: C1#2.2, C2.1, C3#2.1, C4#2.2, C5#2.2, C6#2.1, C7#2.2, C8#2.2, IC1#2.3, IC1#2.5, IC1#2.21, IC2#2.1, IC9.26, J4.4, P1.2, P2.6, P3.1, P3.2, P4.3, P5.3, P6.3, P10.2, R1#2.2, R2#2.2, R3#2.2, R7#2.2, TP9.1, VR2.2
/CC_IRQ: C2.2, IC1#2.8, IC9.14, J4.1, R10.2, S1.2, TP6.1, Y1.2
/CC_MISO: C3#2.2, IC1#2.7, IC9.13, J8.1, Y1.1
/CC_MOSI: C6#2.2, IC1#2.20, IC9.15, J8.4
/CC_SCK: C7#2.1, IC2#2.3, IC9.17, J8.3, JP1.2, P10.1
/CC_SEL: C9#2.1, IC1#2.29, IC9.12, J4.5, P2.5, TP10.1, VR3.2
/DC_IN: C9#2.2, D2.2, D6.2, J2.1, P3.6, Q1.1
/POT_0: IC1#2.32, J4.3, P7.1, TP8.1, VR1.2
/SW_1: IC1#2.9, J4.2, P4.4, TP7.1
/USB_CTS: IC1#2.10, IC7.6, J3.2, P5.4
/USB_DM: IC1#2.11, IC7.9, P6.4, R2.2
/USB_DP: IC1#2.12, IC7.8, R3.2, R6#2.2
/USB_RTS: IC1#2.15, IC7.2, J3.6, P2.4
/USB_RX: IC1#2.16, IC7.4, J3.5, P2.1
/USB_TX: IC1#2.17, IC7.1, J3.4, P2.3
/VSUP: C3.1, C8.1, C15.2, IC1.2, IC3.3, IC3.7, IC3.8, J7.1, L1.2, R4.1
/V_FTDI: C14.1, IC1#2.27, IC7.3, IC7.10, IC7.11, LED1.2, LED2.2, P7.4
/V_LED: C19.1, C31.1, D4.1, D6.1, IC1#2.28, J5.1, P7.5, R6.2
/V_USB: C7.2, C16.1, D3.2, F1.2, IC1#2.23, IC7.12, P4.5, R3#2.1
GND: BT1.2, C1.2, C3.2, C4.1, C5.2, C6.2, C7.1, C8.2, C9.2, C13.2, C14.2, C15.1, C16.2, C18.2, C19.2, C20.2, C27.2, C28.1, C29.1, C30.2, C31.2, IC1.0, IC1.1, IC1.5, IC1#2.24, IC2.2, IC6.1, IC7.5, IC7.13, IC9.1, IC9.9, IC9.10, IC9.11, IC9.16, IC9.18, IC9.20, IC9.21, IC9.22, IC9.25, IC9.31, IC9.32, IC9.33, IC9.34, IC9.36, IC9.37, IC9.38, IC9.39, IC9.40, IC9.41, IC9.42, IC9.43, IC9.44, IC9.45, IC9.46, J1.5, J2.2, J3.1, J5.2, J7.2, J8.6, J9.2, J9.3, JP3.3, L2.2, L3.2, P5.5, Q1.2, R1.1, R2#2.1, R5.2, S1.1, VR1.3, VR2.3, VR3.3
unnamed: AE1.1, C22.1, IC1#2.25, L2.1, P6.5, R1#2.1
unnamed: BT1.1, C9.1, IC2.3, IC3.5, IC3.6
unnamed: C4.2, F1.1, IC1#2.13, J1.1
unnamed: C5.1, IC1#2.14, J1.2, R2.1
unnamed: C6.1, IC1#2.19, J1.3, P8.2, R3.1
unnamed: C13.1, D2.1, IC6.3
unnamed: C18.1, IC1.4, IC1#2.26, P7.3, R7.1
unnamed: C22.2, C24.2, IC1#2.30, L3.1, P3.4
unnamed: C24.1, C26.1, IC1#2.31, IC9.35, P3.5
unnamed: C26.2, J9.1, LED1#2.1, R6#2.1
unnamed: C29.2, LED2#2.1, R7.2, R7#2.1
unnamed: C30.1, IC1.7, IC1#2.2
unnamed: D4.2, IC1.8, IC1#2.22, L1.1, P8.1
unnamed: IC1.3, JP1.1, P1.1, P4.1, P5.1, P6.1, Q1.3, R4.2
unnamed: IC1.6, IC1#2.1, P7.2, R5.1, R6.1
unnamed: IC7.7, R9.1
unnamed: IC7.14, R8.1
unnamed: IC9.2, TP1.1
unnamed: IC9.4, TP2.1
unnamed: IC9.5, IC9.7, JP3.1, JP3.2
unnamed: IC9.6, TP4.1
unnamed: IC9.8, TP5.1
unnamed: IC9.24, TP3.1
unnamed: IC9.27, R13.2
unnamed: IC9.28, R13.1
unnamed: IC9.29, R12.2
unnamed: IC9.30, R12.1
unnamed: LED1.1, R8.2
unnamed: LED2.1, R9.2
VCC: C27.1, C28.2, IC9.19, IC9.23, J3.3, J8.2, R10.1, VR1.1, VR2.1, VR3.1

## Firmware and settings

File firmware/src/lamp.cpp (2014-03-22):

// lamp
// Copyright 2014 by Wiley Cousins, LLC.
// shared under the terms of the MIT License
//
// file: lamp.cpp
// description: application file for the lamp

// avr includes
#include <stdlib.h>
#include <avr/io.h>
#include <avr/interrupt.h>
#include <util/delay.h>

// pin definitions
#include "pindefs.h"

// application includes
#include "lamp.h"

// led serial ISR
ISR(TIMER0_COMPA_vect) {
  if (currentStackSize && !wait) {
    // 1 wire serial
    // pulse the data line once to signal data
    PORTD |= (1<<(2+currentStack));
    PORTD &= ~(1<<(2+currentStack));

    // if data is a one, pulse again to signal a 1
    // no pulse is a 0
    if (currentStackData[byteIndex] & bitIndex) {
      PORTD |= (1<<(2+currentStack));
      PORTD &= ~(1<<(2+currentStack));
    }

    // increment counters
    bitIndex >>= 1;
    // if bit index is at zero, then it's time for a new byte
    if (bitIndex == 0) {
      if (byteIndex < 5) {
        bitIndex = (1<<7);
        byteIndex++;
      }
      // if we get here we've done all the bytes in a card
      else {
        cardCount++;
        // more cards to program
        if (cardCount < currentStackSize) {
          wait = true;
          waitCount = 0;
          currentStackData += 6;
        }
        // no more cards to program
        else {
          stopTimer();
        }
      }
    }
  }
  else if (currentStackSize == 0) {
    stopTimer();
  }
  // stop waiting if it's been long enough
  else if (++waitCount > LED_WAIT_COUNT) {
   wait = false;
   byteIndex = 0;
   bitIndex = (1<<7);
  }
}

// main method
int main(void) {
  // diable global interrupts
  cli();

  // set the heartbeat LED as an output and turn it off
  // heartbeat is on B1
  DDRB |= (1<<1);
  PORTB |= (1<<1);

  // set stack 0 serial data to output and pull it low
  for (uint8_t i=0; i<NUM_STACKS; i++) {
    DDRD |= (1<<(2+i));
    PORTD &= ~(1<<(2+i));
  }

  // init all other pins to inputs with pullups
  initUnusedPins();

  // find out how many led cards are in each stack, and create data arrays for each
  uint8_t *stack[NUM_STACKS];
  uint8_t stackSize[NUM_STACKS];
  senseStacks(stackSize);
  for (uint8_t i=0; i<NUM_STACKS; i++) {
    if (stackSize[i] > 0) {
      stack[i] = initDataArray(stackSize[i]);
    }
  }

  // intialize the led data timer
  initTimer();

  // color blending and shit
  // start with just a little red
  //uint16_t red = 1000;
  //uint16_t grn = 0x0;
  //uint16_t blu = 0x0;


  // stack 0 starts at red
  if (stackSize[0] >= 1) {
    set(4000, 0, 0, 0, stack[0]);
  }
  if (stackSize[0] >= 2) {
    set(2000, 2000, 0, 1, stack[0]);
  }

  // stack 1 starts at green
  if (stackSize[1] >= 1) {
    set(0, 4000, 0, 0, stack[1]);
  }
  if (stackSize[1] >= 2) {
    set(0, 2000, 2000, 1, stack[1]);
  }


  // stack 2 starts at blue
  if (stackSize[2] >= 1) {
    set(0, 0, 4000, 0, stack[2]);
  }
  if (stackSize[2] >= 2) {
    set(2000, 0, 2000, 1, stack[2]);
  }



  // enable global interrupts
  sei();

  if (stackSize[0]) {
    // for testing, set ledData to stack0 data
    currentStack = 0;
    currentStackData = stack[0];
    currentStackSize = stackSize[0];
    startTimer();
  }

  // don't stop believing
  for (;;) {
    /*
    if (!blu && red) {
      red -= 50;
      grn += 50;
    }
    else if (!red && grn) {
      grn -= 50;
      blu += 50;
    }
    else if (!grn && blu) {
      blu -= 50;
      red += 50;
    }
    */
    // if timer is not currently going
    if (!TIMSK0) {
      currentStack = (currentStack < 2) ? (currentStack+1) : 0;
      currentStackData = stack[currentStack];
      currentStackSize = stackSize[currentStack];
      startTimer();
    }

    // set that color and send the data
    //set(red, grn, blu, ledData);
    //set(red, grn, blu, 0, stack[0]);
    //startTimer();

    // BLINK THAT LED LIKE IT'S YOUR JOB
    PINB |= (1<<1);
    _delay_ms(100);
  }
  // hold on to that feeling
  return 42;
}

void initTimer(void) {
  // use 8 bit timer 0
  // looking for f = 230.4 kHz
  // set to CTC mode with prescaler at 64 and top at 1 
  TCCR0A = (1<<WGM01);
  TCCR0B = ( (1<CS01) | (1<<CS00) );
  OCR0A = 1;
}

void startTimer(void) {
  // reset the data indices
  cardCount = 0;
  byteIndex = 0;
  bitIndex = (1<<7);
  // reset the wait flag
  wait = false;
  // enable the interrupt
  TIMSK0 = (1<<OCIE0A);
}

void stopTimer(void) {
  TIMSK0 = 0;
}

void set(uint16_t red, uint16_t grn, uint16_t blu, uint8_t *d) {
  d[0] = 0x3A;
  d[1] = (0xA0 | (red >> 8));
  d[2] = (red & 0xFF);
  d[3] = (grn >> 4);
  d[4] = (((grn<<4) & 0xF0) | (blu >> 8));
  d[5] = (blu & 0xFF);
}

// set led color of a certain led in a certain stack
void set(uint16_t red, uint16_t grn, uint16_t blu, uint8_t led, uint8_t *data) {
  uint8_t *d = data + 6*led;
  d[0] = 0x3A;
  d[1] = (0xA0 | (red >> 8));
  d[2] = (red & 0xFF);
  d[3] = (grn >> 4);
  d[4] = (((grn<<4) & 0xF0) | (blu >> 8));
  d[5] = (blu & 0xFF);
}

// initialize analog inputs and sense stack sizes
void senseStacks(uint8_t *size) {
  // analog inputs on D2, D3, D4, so diable digital input on these pins
  DIDR0 = ( (1<<ADC4D) | (1<<ADC3D) | (1<<ADC2D) );
  // reference voltage is AVcc, external capacitor on AREF
  // left adjust result because we only need 8 bits
  // set first read to 1.1V reference voltage (MUX3..0 = 0xE)
  ADMUX = ( (1<<ADLAR) | (1<<REFS0) | (0xE) );
  // divide sysclock by 128 to set fadc to ~100kHz
  // enable the ADC and start a conversion to warm everything up
  ADCSRA = ( (1<<ADEN) | (1<<ADSC) | (1<<ADPS2) | (1<<ADPS1) | (1<<ADPS0) );
  // wait for that conversion to complete
  while (ADCSRA & (1<<ADSC));

  // read the stack sizes
  for (uint8_t i=0; i<NUM_STACKS; i++) {
    // set ADC input to correct input
    ADMUX = ((ADMUX & ~0xF) | (2+i));
    // take the reading
    ADCSRA |= (1<<ADSC);
    while (ADCSRA & (1<<ADSC));
    uint8_t read = ADCH;
    // translate it into stack size
    size[i] = 0;
    if (read > adcToStackSize[MAX_STACK_SIZE]) {
      size[i]++;
      uint8_t prev;
      int8_t next;
      do {
        prev = adcToStackSize[size[i]] - read;
        next = read - adcToStackSize[size[i]+1];
        if ( next < 0 || prev > next) {
          size[i]++;
        }
      } while (next < 0);
    }
  }
}

uint8_t *initDataArray(uint8_t stackSize) {
  stackSize *= 6;
  // calloc malloc's and initializes elements to 0
  return (uint8_t *)(calloc(stackSize, sizeof(uint8_t)));
}

// initialize unused pins to inputs with internal pullups activated
void initUnusedPins(void) {
  // portb unused pins
  DDRB &= ~PORTB_UNUSED_MASK;
  PORTB |= PORTB_UNUSED_MASK;

  // portc unused pins
  DDRC &= ~PORTC_UNUSED_MASK;
  PORTC |= PORTC_UNUSED_MASK;

  // portd unused pins
  DDRD &= ~PORTD_UNUSED_MASK;
  PORTD |= PORTD_UNUSED_MASK;
}

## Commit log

2014-02-26 kicad project file
2014-02-26 component libraries loaded
    [lamp-pcb.sch]
2014-02-26 schematic page formatting
    [lamp-pcb.sch]
2014-02-26 MCU set up with programming and serial headers
    [lamp-pcb.sch]
2014-02-26 got an led driver on there
    [lamp-pcb.sch]
2014-02-26 put a basic volatge regulator on there. may switch it out for something else
    [lamp-pcb.sch]
2014-02-27 first pass at schematic done
    [lamp-pcb.sch]
2014-02-27 stopping point because of new kicad library issues
    [lamp-pcb.sch]
2014-02-28 footprint selection done; moving to layout
    [lamp-pcb.kicad_pcb, lamp-pcb.sch]
2014-02-28 schematic pdf
2014-02-28 board geometry mostly figured out
    [lamp-pcb.kicad_pcb]
2014-03-05 component positions good. need some mounting holes
    [lamp-pcb.kicad_pcb, lamp-pcb.sch]
2014-03-05 mounting holes
    [lamp-pcb.kicad_pcb]
2014-03-05 laying traces
    [lamp-pcb.kicad_pcb]
2014-03-05 layout going well but computer dying
    [lamp-pcb.kicad_pcb, lamp-pcb.sch]
2014-03-06 layout done. getting quotes then gonna clean up
    [lamp-pcb.kicad_pcb]
2014-03-06 adding some first pass gerbers. probably not good for actual fab, but sizing is right for quoting
    [lamp-pcb-B_Cu.gbl, lamp-pcb-B_Mask.gbs, lamp-pcb-B_SilkS.gbo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]
2014-03-06 silkscreen cleaned up. need to figure out how I actually want to panelize
    [lamp-pcb.kicad_pcb]
2014-03-06 i like this panelization layout
    [lamp-pcb.kicad_pcb]
2014-03-13 full panel
    [lamp-pcb.kicad_pcb]
2014-03-13 jk roflcopter. panel is now correct
    [lamp-pcb.kicad_pcb]
2014-03-13 ok this might've finally got it
    [lamp-pcb.kicad_pcb]
2014-03-13 fixed up board outline and fills
    [lamp-pcb.kicad_pcb]
2014-03-13 panel plot
    [lamp-pcb-B_Cu.gbl, lamp-pcb-B_Mask.gbs, lamp-pcb-B_SilkS.gbo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]
2014-03-13 new barebones plots
    [lamp-pcb-B_Cu.gbl, lamp-pcb-Edge_Cuts.gbr, lamp-pcb-F_Cu.gtl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]
2014-03-13 barebones order placed
    [lamp-pcb.kicad_pcb]
2014-03-13 adding bom
    [lamp-pcb-bom.csv]
2014-03-13 fixing up a few minor bom issues
    [lamp-pcb.sch]
2014-03-20 blink heartbeat led
2014-03-21 add missing no-connect to avr pin
    [lamp-pcb.sch]
2014-03-21 add unused pin initilization
2014-03-21 implement led stack size sensing
2014-03-21 does not work in hardware
    [lamp.cpp]
2014-03-21 stack sense correctly senses number of cards in stack
    [lamp.cpp]
2014-03-21 verify that arrays are being calloced correctly and new set function works
    [lamp.cpp]
2014-03-22 done with arduino testing sketch
2014-03-22 pumpz up the jamz
    [lamp.cpp]
2014-04-16 start separating control circuits from led circuits
    [lamp-main.sch]
2014-04-21 rearranging file locations
    [lamp-main.sch]
2014-04-21 this is going somewhere
    [lamp-main.sch]
2014-04-21 move expansion board to separate project
    [lamp-expansion.sch]
2014-04-22 schematic work for expansion board
    [lamp-expansion.sch]
2014-04-22 work in progress
    [lamp-expansion.sch]
2014-04-22 cc3000 schematic diagram done
    [lamp-expansion.sch]
2014-04-22 moving to work on main board
    [lamp-expansion.sch]
2014-04-22 main board edits first pass done
    [lamp-main.sch]
2014-04-23 still need to add boost reg to schematic;
    [lamp-expansion.sch, lamp-main.sch]
2014-04-23 expansion schematic nearly done
    [lamp-expansion.sch]
2014-04-23 i think the schematic is done
    [lamp-expansion.sch]
2014-04-30 schematic passes error checking
    [lamp-expansion.sch]
2014-04-30 ongoing footprint assignment
2014-04-30 kicad bug. building latest revision. hang on
    [lamp-expansion.sch]
2014-04-30 fixed typo for 74L05 LDO value
    [lamp-expansion.sch]
2014-05-01 assign footprints and start layout
    [lamp-expansion.kicad_pcb, lamp-expansion.sch]
2014-05-02 replace boost regulator
    [lamp-expansion.kicad_pcb, lamp-expansion.sch]
2014-05-02 boost regulator work
    [lamp-expansion.sch]
2014-05-02 working on the layout;
    [lamp-expansion.kicad_pcb, lamp-expansion.sch]
2014-05-02 modules grouped in layout;
    [lamp-expansion.kicad_pcb]
2014-05-02 moving over to main board
    [lamp-expansion.sch]
2014-05-02 redoing main layout
    [lamp-main.kicad_pcb]
2014-05-02 add board outline
    [lamp-main.kicad_pcb]
2014-05-02 trying something new
    [lamp-main.kicad_pcb, lamp-main.sch]
2014-05-02 refactor power supply configuration
    [lamp-expansion.sch]
2014-05-07 board layout and schematic refinement
    [lamp-expansion.kicad_pcb, lamp-expansion.sch, lamp-main.kicad_pcb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]
2014-05-07 a little more room fort activities
    [lamp-expansion.kicad_pcb, lamp-expansion.sch]
2014-05-07 continue layout work
    [lamp-expansion.kicad_pcb]
2014-05-08 layout and schematic refinements
    [lamp-expansion.kicad_pcb, lamp-expansion.sch]
2014-05-09 still working on the layout
    [lamp-expansion.sch, lamp-main.kicad_pcb, lamp-main.sch]
2014-05-28 wire up main board
    [lamp-main.kicad_pcb]
2014-05-28 still need to match nets up between main and expansion
    [lamp-expansion.kicad_pcb]
2014-06-02 last few traces
    [lamp-expansion.kicad_pcb]
2014-06-02 safety commit
    [lamp-expansion.kicad_pcb]
2014-10-15 several boards
    [lamp-expansion-bom.csv, lamp-main.sch]
2015-11-04 add changes found after first iMac powerup since 2014
    [lamp-expansion-bom.csv, lamp-expansion.csv, lamp-expansion.sch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]

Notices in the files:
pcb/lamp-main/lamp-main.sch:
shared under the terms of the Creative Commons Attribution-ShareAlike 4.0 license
